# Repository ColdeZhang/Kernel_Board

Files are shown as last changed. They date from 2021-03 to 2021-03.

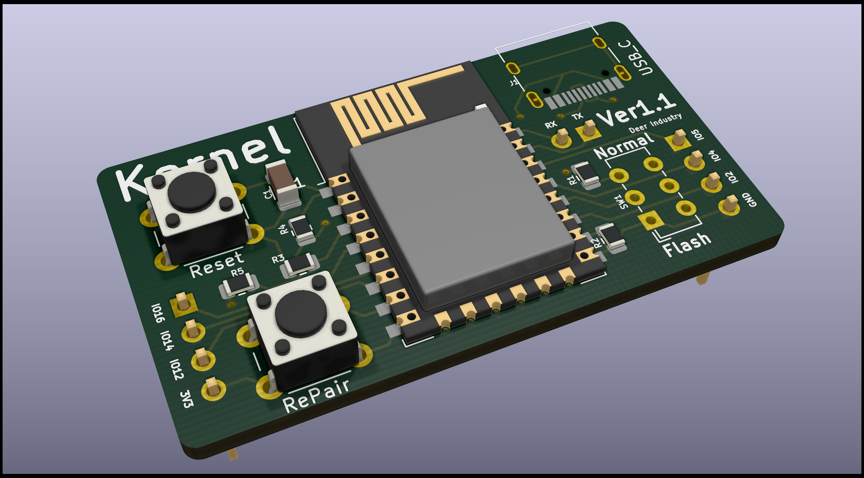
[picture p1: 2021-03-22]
Ver_1_X/Kernel.png

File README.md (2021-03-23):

# Homekit智能家居开发板-核心板（Kernel）



## 0x0 总体概述

- Kernel板主要基于安信可的ESP-12S（后者基于乐鑫ESP8266），为HomeKit智能家居开发准备了一些基础电路。因此更适合没有太多电路基础的新手着手进行Homekit智能家居的开发。相比于ESP-01在保留必须的一部分功能后尽可能的引出了更多的可用IO口（6个），使之可以适应更复杂的项目开发，并且拥有更加稳定的网络连接。项目基于Apple Homekit与ESP8266，并且全部开源。

- 该核心板全部文件托管在：[Github仓库](https://github.com/ColdeZhang/Kernel_Board)

- 该核心板配套的代码教程参见：[ESP8266-Homekit 模板代码](https://github.com/ColdeZhang/Esp8266_Homekit_Template)

- 该核心板配套的扩展版系列目前有：？？、？？、？？、？？

> 从1.0版本开始新增USB-Type-C接口支持供电+烧写程序，无需外接TTL转USB

此页面只显示最新版本开发板的资料，旧版本请移步至具体版本的对应文件夹：[Ver_0_X](https://github.com/ColdeZhang/Kernel_Board/tree/main/Ver_0_X)

## 0x1 特点

### 1.复位功能

- Reset按键可以实行一键重启，免除了切换模式时需要拔插电源重启的麻烦。

### 2.模式切换

- 由于ESP-12S具有两种模式（运行模式与烧写模式），并且需要通过将IO0接地来手动切换。本核心板将此操作使用一个单刀双掷开关（SW1）集成在主板上，可以通过拨动开关一键切换运行模式（Normal）和烧写模式（Flash）。

### 3.重新配对

- 因为配对信息是被写入在ESP-12S的闪存中的，所以通过Reset是无法擦除配对记录来重新配对的。
- 如果需要重新配对需要调用Apple Homekit内置函数来执行闪存内信息的重写，在本核心板配套的[Template代码](https://github.com/ColdeZhang/Esp8266_Homekit_Template)中，该功能已被写在了IO13引脚上。
- 硬件层面通过一个按钮RePair，按下即可重新配对。

### 4.恰到好处的尺寸

- 该核心板拥有恰到好处的尺寸（宽5cm），使其恰好能够放入一个常规开关盒中，十分适合用来制作一些实用的智能家居设备。

## 0x2 使用方法

### 1.运行方法

1. 将右下的开关选择至Normal；
2. 在任意的一个3V3引脚上连接3.3v的直流正极，任意一个GND引脚连接相应的负极即可启动开发板。
3. 在开发中如果需要重启开发板，可以直接按下主控板上的Reset按键执行重启。（该操作不会擦除ESP-12S上内存与闪存的数据）

### 2.烧写程序

1. 将右下的开关选择至Flash，按下Reset按钮执行重启，重启后主控板处于烧写模式；

2. 将USB-Type-C数据线连接至核心板，另一段连接至电脑，即可从电脑烧写程序至开发板了；
3. 烧写完成后需要将开关切换回Normal模式，再按下重启按钮；

## 0x3 外观尺寸



## 0x4 管脚定义

略

## 0x5 原理图



## 0x6 二次开发说明

1. 本项目全部开源，可直接从仓库获得所有工程文件；
2. 项目电路图、pcb以及Gerber文件的生成全部使用[KiCad](https://www.kicad.org)操作（工程文件后缀为pro）；
3. 项目从成本的角度出发，仅使用了单层电路板；
4. 为了便于焊接，在元器件布局以及选型上都并不是电路设计理论上的最优解；
5. 其中ESP-12S可自由替换ESP-12F或同系列芯片；

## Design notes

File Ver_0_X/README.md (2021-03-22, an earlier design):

# Homekit智能家居开发板-核心板（Kernel）



## 0x0 总体概述

Kernel板主要基于安信可的ESP-12S（后者基于乐鑫ESP8266），为HomeKit智能家居开发准备了一些基础电路。因此更适合没有太多电路基础的新手着手进行Homekit智能家居的开发。相比于ESP-01在保留必须的一部分功能后尽可能的引出了更多的可用IO口（6个），使之可以适应更复杂的项目开发，并且拥有更加稳定的网络连接。项目基于Apple Homekit与ESP8266，并且全部开源。

该核心板全部文件托管在：[Github仓库](https://github.com/ColdeZhang/Kernel_Board)

该核心板配套的代码教程参见：[ESP8266-Homekit 模板代码](https://github.com/ColdeZhang/Esp8266_Homekit_Template)

该核心板配套的扩展版系列目前有：？？、？？、？？、？？

> 在0.1版本中Flash（烧写）模式被称为Upload（上传）模式
>
> 从1.0版本开始新增USB-Type-C接口支持供电+烧写程序，无需外接TTL转USB

## 0x1 特点

### 1.复位功能

Reset按键可以实行一键重启，免除了切换模式时需要拔插电源重启的麻烦。

### 2.模式切换

由于ESP-12S具有两种模式（运行模式与烧写模式），并且需要通过将IO0接地来手动切换。本核心板将此操作使用一个单刀双掷开关（SW1）集成在主板上，可以通过拨动开关一键切换运行模式（Normal）和烧写模式（Flash）。

### 3.重新配对

因为配对信息是被写入在ESP-12S的闪存中的，所以通过Reset是无法擦除配对记录来重新配对的。如果需要重新配对需要调用Apple Homekit内置函数来执行闪存内信息的重写，在本核心板配套的Template代码中，该功能已被写在了IO13引脚上。硬件层面通过一个按钮RePair，按下即可重新配对。

### 4.恰到好处的尺寸

该核心板拥有恰到好处的尺寸（宽5cm），使其恰好能够放入一个常规开关盒中，十分适合用来制作一些实用的智能家居设备。而从成本（一般来说越小的元件价格越高）与加工难度（越复杂的电路加工难度越大）的角度考虑，并没有将其做的十分小巧的必要。

## 0x2 使用方法

### 1.运行方法

将右下的开关选择至Normal，在任意的一个3V3引脚上连接3.3v的直流正极，任意一个GND引脚连接相应的负极即可启动开发板。在开发中如果需要重启开发板，不需要断开电源重连，可以直接按下主控板上的Reset按键执行重启。（该操作不会擦除ESP-12S上内存与闪存的数据）

### 2.烧写程序

将右下的开关选择至Flash，按下Reset按钮执行重启，重启后主控板处于烧写模式。

#### 对于1.0以下的版本

将USB转TTL串口烧写器的对应引脚连接至开发板右上一排引脚TX、RX、3V3、GND，再将烧写器连接至电脑，即可从电脑烧写程序至开发板。烧写完成后需要将开关切换回Normal模式，再按下重启按钮。

#### 对于1.0以上的版本

将USB-Type-C数据线连接至核心板，另一段连接至电脑，即可从电脑烧写程序至开发板。烧写完成后需要将开关切换回Normal模式，再按下重启按钮。

## 0x3 外观尺寸



## 0x4 管脚定义

略

## 0x5 原理图



## 0x6 二次开发说明

1. 本项目全部开源，可直接从仓库获得所有工程文件；
2. 项目电路图、pcb以及Gerber文件的生成全部使用[KiCad](https://www.kicad.org)操作（工程文件后缀为pro）；
3. 项目从成本的角度出发，仅使用了单层电路板；
4. 为了便于焊接，在元器件布局以及选型上都并不是电路设计理论上的最优解；
5. 其中ESP-12S可自由替换ESP-12F或同系列芯片；

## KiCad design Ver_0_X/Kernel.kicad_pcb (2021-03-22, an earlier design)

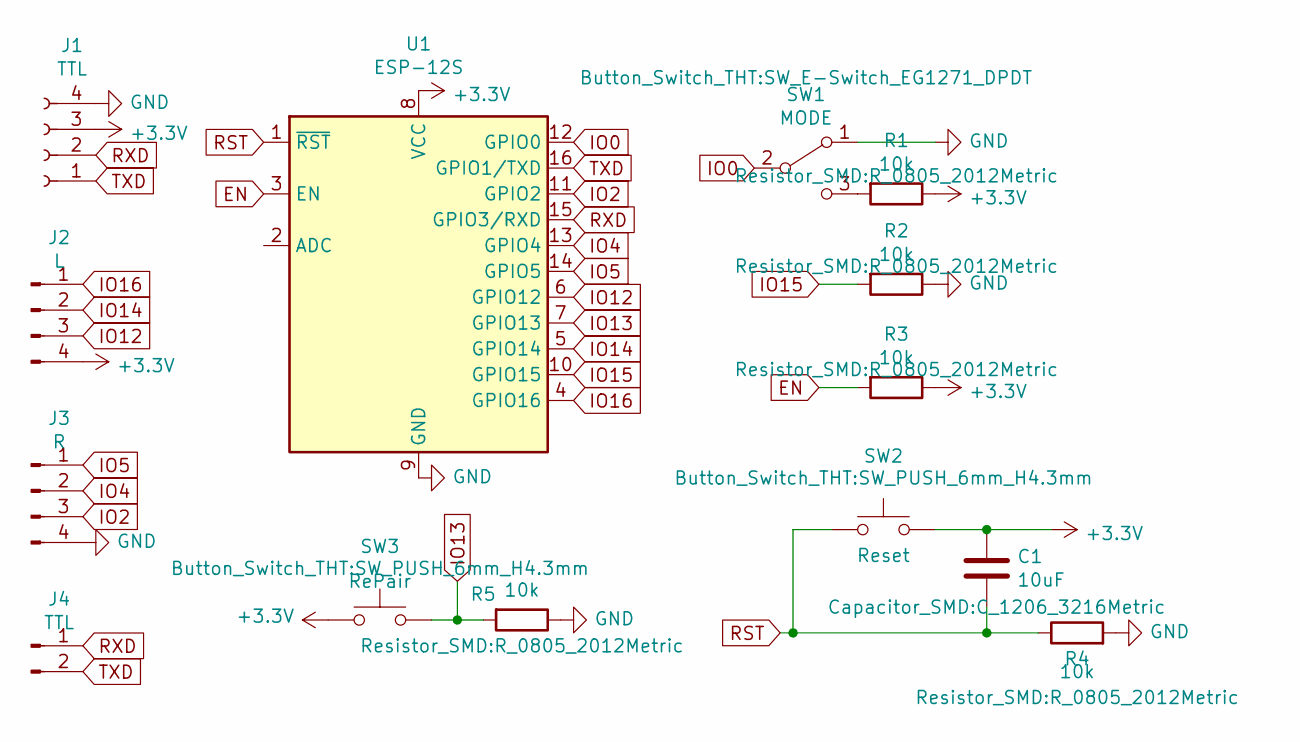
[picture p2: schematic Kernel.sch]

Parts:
C1: 10uF; C_1206_3216Metric
J1: TTL; PinHeader_1x04_P2.54mm_Horizontal
J2: L; PinHeader_1x04_P2.54mm_Vertical
J3: R; PinHeader_1x04_P2.54mm_Vertical
J4: TTL; PinHeader_1x02_P2.54mm_Vertical
R1, R2, R3, R4, R5: 10k; R_0805_2012Metric
SW1: MODE; SW_E-Switch_EG1271_DPDT
SW2: Reset; SW_PUSH_6mm_H4.3mm
SW3: RePair; SW_PUSH_6mm_H4.3mm
U1: ESP-12S

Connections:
+3V3: C1.1, J1.3, J2.4, R1.1, R3.1, SW2.2, SW3.1, U1.8 (VCC)
EN: R3.2, U1.3 (EN)
GND: J1.4, J3.4, R2.1, R4.2, R5.1, SW1.1 (A), U1.9 (GND)
IO0: SW1.2 (B), U1.12 (GPIO0)
IO2: J3.3, U1.11 (GPIO2)
IO4: J3.2, U1.13 (GPIO4)
IO5: J3.1, U1.14 (GPIO5)
IO12: J2.3, U1.6 (GPIO12)
IO13: R5.2, SW3.2, U1.7 (GPIO13)
IO14: J2.2, U1.5 (GPIO14)
IO15: R2.2, U1.10 (GPIO15)
IO16: J2.1, U1.4 (GPIO16)
unnamed: R1.2, SW1.3 (C)
RST: C1.2, R4.1, SW2.1, U1.1 (~RST)
RXD: J1.2, J4.1, U1.15 (GPIO3/RXD)
TXD: J1.1, J4.2, U1.16 (GPIO1/TXD)

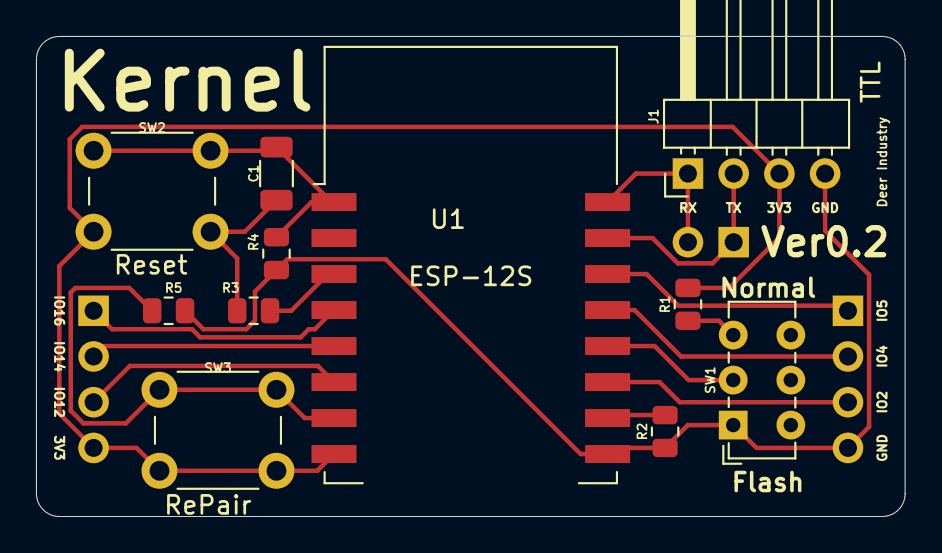
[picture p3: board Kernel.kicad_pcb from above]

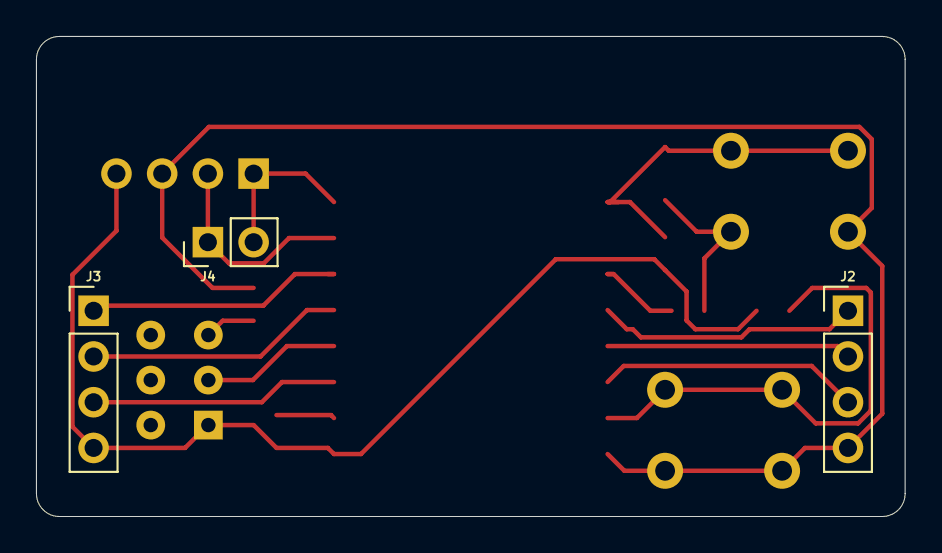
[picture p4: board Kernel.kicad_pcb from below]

Board: 2 copper layers, 48.3 x 26.7 mm, 14 parts (3 on the bottom side), 16 nets.

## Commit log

2021-03-17 update files
    [Kernel-B_Cu.gbl, Kernel-B_Mask.gbs, Kernel-B_Paste.gbp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]
2021-03-22 update Ver 1.1
    [Kernel-B_Cu.gbl, Kernel-B_Mask.gbs, Kernel-B_Paste.gbp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]
2021-03-23 fixed reset
    [Kernel-B_Cu.gbl, Kernel-B_Mask.gbs, Kernel-B_Paste.gbp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]
